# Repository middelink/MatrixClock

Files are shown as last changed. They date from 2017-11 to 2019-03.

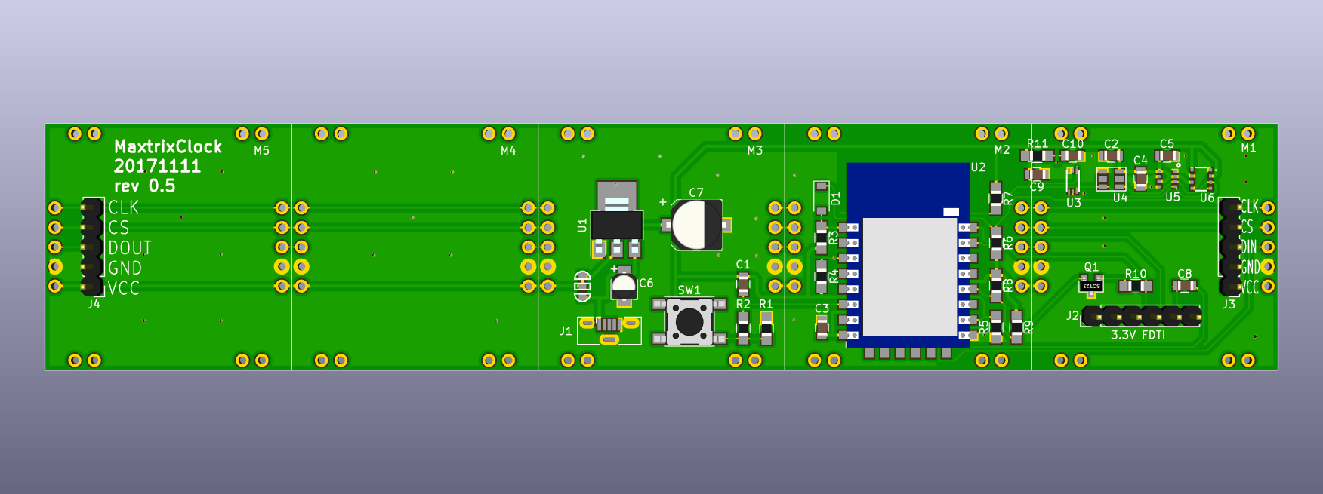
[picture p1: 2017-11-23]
KiCad/MatrixClock.png

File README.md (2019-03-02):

# MatrixClock



## TL;DR

MatrixClock is both a hardware and software project to create an extensible
40x8 dot matrix display with some sensors attached because, uhm. I could?

Here you will find the both the schematics, pcb layout and source code of my
MatrixClock project.

## Features

* Based on generaly available red 8x8 dot matrix displays with MAX7219. E.g. on [eBay](https://www.ebay.com/itm/8x8-3mm-5mm-Dot-Matrix-Display-Red-Full-Color-RGB-LED-MAX7219-DIY-Kit-f-Arduino/401374736108) (the red one, with the yellow headers).
* Full source code (arduino, platformio)
* Full schematics, PCB layout and gerbers (kicad)
* ESP-12E/F module for driving display and ntp time keeping.
* USB powered
* User defined button
* Light sensor: APDS9301 and/or BH1750FVI
* Environment sensor: BME280 or BME680
* Extensible, units can be cascaded (only one should have active components though)

## Libraries

* Adafruit's BME680 library has the nasty habbit of initializing the Wire
  library instead of leaving that to the calling program. This means they
  override our carefully set non-standard I2C pins. Needs to be commented
  out around line 104 in Adafruit\_BME680.cpp.
* Same library, Adafruit\_BME680.h, you want to comment out the include of
  Adafruit\_sensor.h. Not there, not used, not needed.

## Installation

The source is written on a Linux box and compiled/uploaded via the excellent
[PlatformIO](https://platformio.org) toolkit. The schematics and pcb layout is
created in [KiCad](https://kicad-pcb.org).

I will not bother to tell you how to compile/upload the code, modify the
schema, change the layout, create gerbers and wait patiently for the PCBs
to arrive before starting your SMD soldering adventure. Simply because
you should not do this if you not exhaustively researched all of the
just mentioned area's.

Good luck!
  Pauline

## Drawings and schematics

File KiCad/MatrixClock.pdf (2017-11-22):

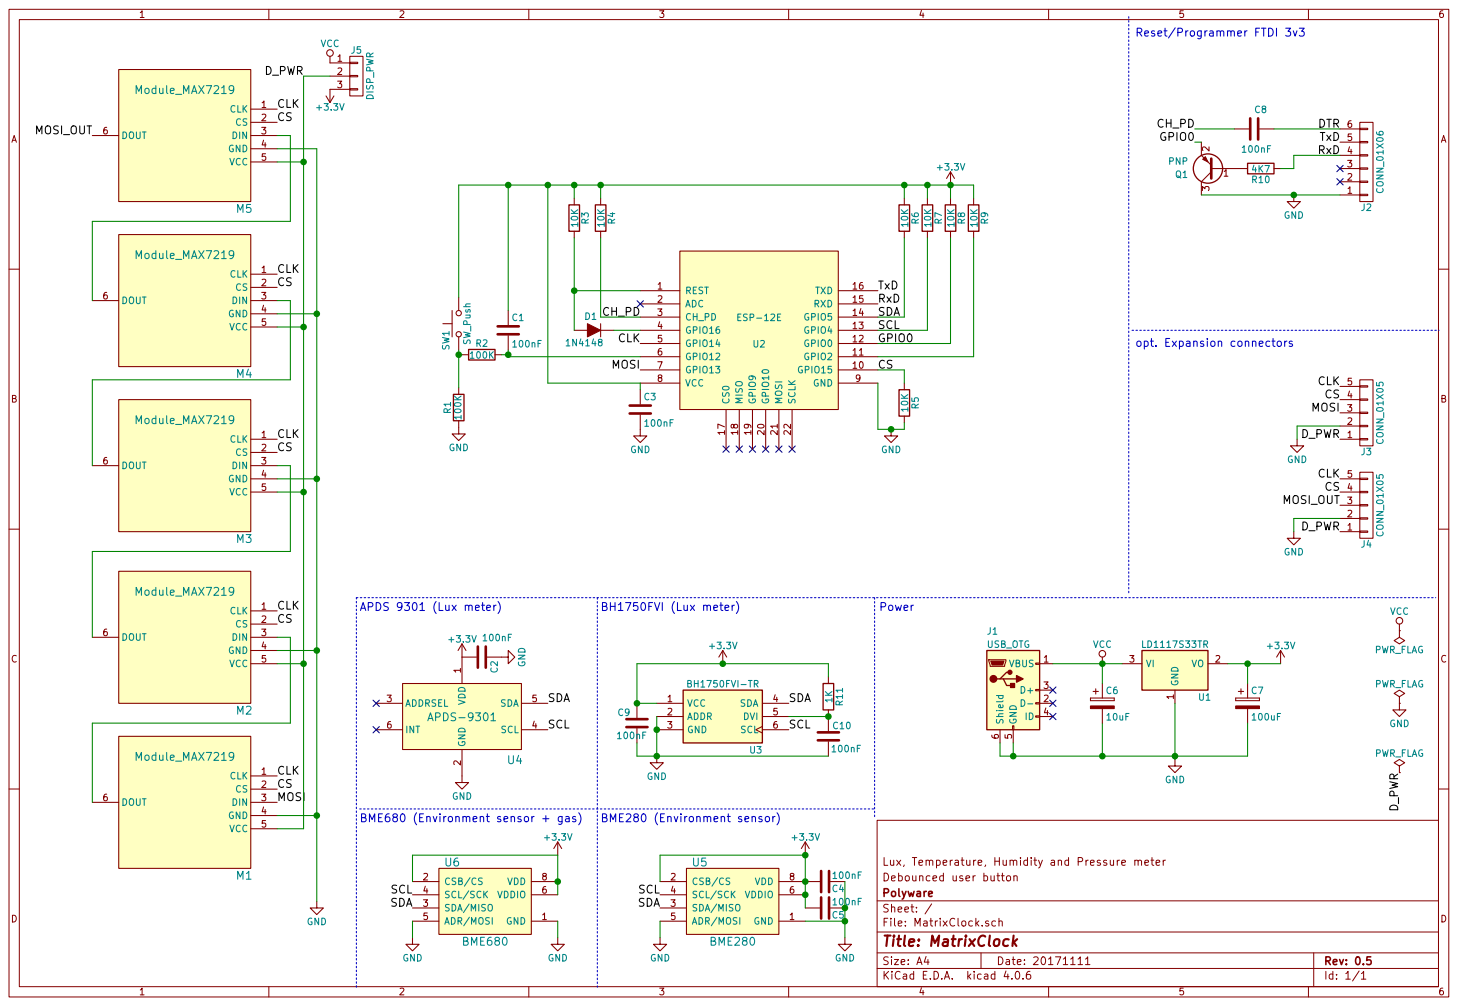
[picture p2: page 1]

BH1750FVI (Lux meter)

SCL C2 +3.3V 100nF GND

Lux, Temperature, Humidity and Pressure meter
File: MatrixClock.sch Sheet: / Polyware Debounced user button

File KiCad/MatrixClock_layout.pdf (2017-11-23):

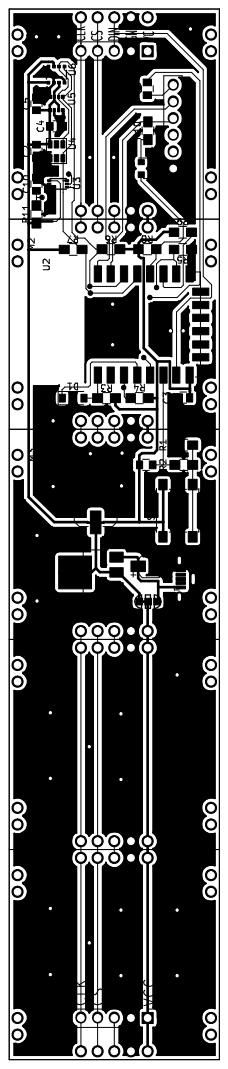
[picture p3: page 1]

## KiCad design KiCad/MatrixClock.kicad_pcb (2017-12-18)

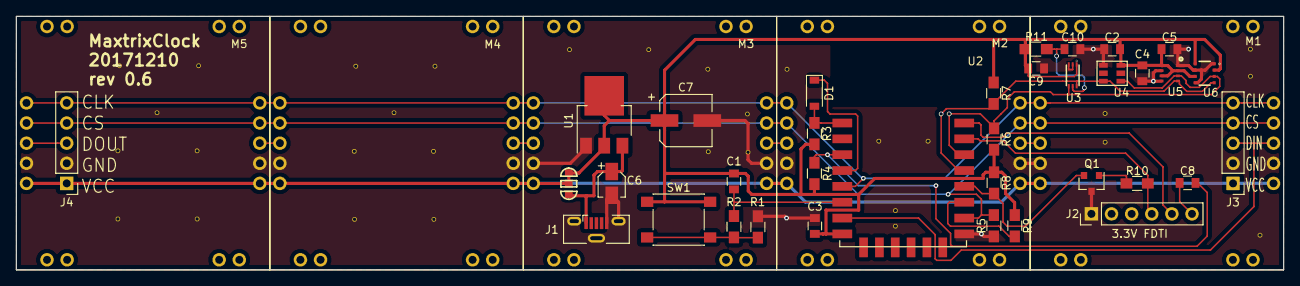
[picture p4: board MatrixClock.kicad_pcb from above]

Board: 2 copper layers, 160.0 x 32.0 mm, 70 parts (0 on the bottom side), 26 nets.

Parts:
C1, C2, C3, C4, C5, C8, C9, C10: 100nF; C_0805
C6: 10uF; CP_Elec_3x5.3
C7: 100uF; CP_Elec_6.3x5.7
D1: 1N4148; D_SOD-123
J1: USB_OTG; USB_Micro-B_Vertical_Molex-105133-0001
J2: CONN_01X06; Pin_Header_Straight_1x06_Pitch2.54mm
J3, J4: CONN_01X05; Pin_Header_Straight_1x05_Pitch2.54mm
J5: DISP_PWR; SOLDER-JUMPER_2-WAY
M1, M2, M3, M4, M5: Module_MAX7219
Q1: PNP; SOT-23
R1, R2: 100K; R_0805_HandSoldering
R3, R4, R5, R6, R7, R8, R9: 10K; R_0805_HandSoldering
R10: 4K7; R_0805_HandSoldering
R11: 1K; R_0805_HandSoldering
SW1: SW_Push; SW_SPST_PTS645
U1: LD1117S33TR; SOT-223-3Lead_TabPin2
U2: ESP-12E; ESP-12E_SMD
U3: BH1750FVI-TR; WSOF6
U4: APDS-9301; APDS9301
U5: BME280
U6: BME680
VIA01, VIA02, VIA03, VIA04, VIA05, VIA06, VIA07, VIA07#2, VIA08, VIA09, VIA10, VIA11, VIA12, VIA13, VIA14, VIA15, VIA17, VIA20, VIA21, VIA22, VIA23, VIA23#2, VIA23#3, VIA24, VIA26, VIA26#2, VIA27, VIA28, VIA29, VIA31: VIA-6mm

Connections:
+3V3: C1.1, C2.2, C3.1, C4.2, C5.2, C7.1, C9.2, J5.3, R3.1, R4.1, R6.1, R7.1, R8.1, R9.1, R11.1, SW1.1, U1.2, U2.8, U3.1, U4.1, U5.2, U5.6, U5.8, U6.2, U6.6, U6.8
/CH_PD: C8.2, R4.2, U2.3
/CLK: J3.5, J4.5, M1.1, M2.1, M3.1, M4.1, M5.1, U2.5
/CS: J3.4, J4.4, M1.2, M2.2, M3.2, M4.2, M5.2, R5.1, U2.10
/DTR: C8.1, J2.6
/D_PWR: J3.1, J4.1, J5.2, M1.5, M2.5, M3.5, M4.5, M5.5
/GPIO0: Q1.2, R8.2, U2.12
/MOSI: J3.3, M1.3, U2.7
/MOSI_OUT: J4.3, M5.6
/RxD: J2.4, R10.1, U2.15
/SCL: R7.2, U2.13, U3.6, U4.4, U5.4, U6.4
/SDA: R6.2, U2.14, U3.4, U4.5, U5.3, U6.3
/TxD: J2.5, U2.16
GND: C2.1, C3.2, C4.1, C5.1, C6.2, C7.2, C9.1, C10.1, J1.5, J1.6, J2.1, J3.2, J4.2, M1.4, M2.4, M3.4, M4.4, M5.4, Q1.3, R1.1, R5.2, U1.1, U2.9, U3.2, U3.3, U4.2, U5.1, U5.5, U5.7, U6.1, U6.5, U6.7, VIA01.1, VIA02.1, VIA03.1, VIA04.1, VIA05.1, VIA06.1, VIA07.1, VIA07#2.1, VIA08.1, VIA09.1, VIA10.1, VIA11.1, VIA12.1, VIA13.1, VIA14.1, VIA15.1, VIA17.1, VIA20.1, VIA21.1, VIA22.1, VIA23.1, VIA23#2.1, VIA23#3.1, VIA24.1, VIA26.1, VIA26#2.1, VIA27.1, VIA28.1, VIA29.1, VIA31.1
unnamed: C1.2, R2.1, U2.6
unnamed: C10.2, R11.2, U3.5
unnamed: D1.1, U2.4
unnamed: D1.2, R3.2, U2.1
unnamed: M1.6, M2.3
unnamed: M2.6, M3.3
unnamed: M3.6, M4.3
unnamed: M4.6, M5.3
unnamed: Q1.1, R10.2
unnamed: R1.2, R2.2, SW1.2
unnamed: R9.2, U2.11
VCC: C6.1, J1.1, J5.1, U1.3

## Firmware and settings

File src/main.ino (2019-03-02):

// vim:softtabstop=4:shiftwidth=4:tabstop=64:filetype=cpp
#include <ESP8266WiFi.h>
#include <ESP8266mDNS.h>
#include <ArduinoOTA.h>
#include <FS.h>
#include <Ticker.h>
#include <Wire.h> 
#include <SPI.h>
#include <time.h>
#include <list>

#include "MD_MAX72xx.h"
#include <ArduinoJson.h>
#include <WiFiManager.h> 
#include <PubSubClient.h>
#include <Bounce2.h>
#include "apds9301.h"
#include <Adafruit_BME680.h>
#include <BH1750.h>
#include <BME280I2C.h>
#include <EnvironmentCalculations.h>

#define HAS_APDS9301  // Light meter
#define HAS_BH1750    // Light meter
#define HAS_BME280    // Env meter
#define HAS_BME680    // Env meter + gas

/* constants */
constexpr auto _SDA = 5;
constexpr auto _SCL = 4;

constexpr char tz[] = "TZ=CET-1CEST-2,M3.5.0/02:00:00,M10.5.0/03:00:00";

constexpr auto BUTTON = 12;

/* global variables */
MD_MAX72XX leds(SS, 5);
Ticker ticker1;
Bounce bouncy;
int display_mode;
int display_time;
bool show_time;

//define your default values here, if there are different values in config.json, they are overwritten.
String mqtt_server("rp1.ch.polyware.nl");
String mqtt_port("1883");
bool shouldSaveConfig;

uint32_t press_time;
uint32_t delay_next;
uint32_t delay_next_sensors;
#if defined(HAS_BME280) || defined(HAS_BME680)
enum {
    ENV_UNKNOWN,
    ENV_BME280,
    ENV_BME680,
} bme;
#endif
#if defined(HAS_APDS9301) || defined(HAS_BH1750)
enum {
    LUX_UNKNOWN,
    LUX_APDS9301,
    LUX_BH1750,
} lux;
#endif
#ifdef HAS_APDS9301
LuxI2C_APDS9301 apds(0x39);
#endif
#ifdef HAS_BH1750
BH1750 bh;
#endif
#ifdef HAS_BME280
BME280I2C bme280(BME280I2C::Settings{
    /*tosr=*/BME280::OSR_X1,
    /*hosr=*/BME280::OSR_X1,
    /*posr=*/BME280::OSR_X1,
    /*mode=*/BME280::Mode_Forced,
    /*st=*/BME280::StandbyTime_1000ms,
    /*filter=*/BME280::Filter_Off,
    /*spiEnable=*/BME280::SpiEnable_False,
    /*bme_280_addr=*/BME280I2C::I2CAddr::I2CAddr_0x76});
#endif
#ifdef HAS_BME680
Adafruit_BME680 bme680;
#endif
String mqtt_prefix;
WiFiClient wificlient;
PubSubClient mqtt("", 0, wificlient);

// Setup ESP to measure VCC
ADC_MODE(ADC_VCC);

void setString(const char* msg) {
    int offset = leds.getColumnCount()-1;
    leds.control(MD_MAX72XX::UPDATE, MD_MAX72XX::OFF);
    leds.clear();
    while (char ch = *msg++) {
        offset -= leds.setChar(offset, ch) + 1;
    }
    leds.control(MD_MAX72XX::UPDATE, MD_MAX72XX::ON);
}

void setString(float val, const char suffix[]) {
    String s(val, 0);
    s += suffix;

    int offset = -2;
    uint8_t buf[8];
    for (const auto &ch : s) {
        offset += leds.getChar(ch, sizeof(buf), buf) + 1;
    }
    for (const auto &ch : s) {
        offset -= leds.setChar(offset, ch) + 1;
    }
}

struct {
    float volt;
    float lux;
    float temp;
    float hum;
    float dew;
    float pres;
    float gas_r;
} sensors;

void showTime(void) {
    time_t now = time(nullptr);
    if (now == 0)
        return;
    struct tm *tm = localtime(&now);

    show_time = true;

    leds.control(MD_MAX72XX::UPDATE, MD_MAX72XX::OFF);
    leds.clear();
    switch (display_mode) {
        case 4: // Temp
            setString(sensors.temp, "\775C");
            if (--display_time == 0) {
                display_mode--;
                display_time = 5;
            }
            break;
        case 3: // RH
            setString(sensors.hum, " RH");
            if (--display_time == 0) {
                display_mode--;
                display_time = 5;
            }
            break;
        case 2: // hPA
            setString(sensors.pres, " hPa");
            if (--display_time == 0) {
                display_mode--;
                display_time = 5;
            }
            break;
        case 1: // Lux
            setString(sensors.lux, " lx");
            if (--display_time == 0) {
                display_mode--;
                display_time = 5;
            }
            break;
        case 0:
            leds.setChar(38, '0'+(tm->tm_hour/10)%10);
            leds.setChar(32, '0'+(tm->tm_hour/ 1)%10);
            leds.setChar(26, ':');
            leds.setChar(24, '0'+(tm->tm_min/10)%10);
            leds.setChar(18, '0'+(tm->tm_min/ 1)%10);
            leds.setChar(12, ':');
            leds.setChar(10, '0'+(tm->tm_sec/10)%10);
            leds.setChar( 4, '0'+(tm->tm_sec/ 1)%10);
            break;
    }
    leds.control(MD_MAX72XX::UPDATE, MD_MAX72XX::ON);
}

void readSensors() {
    sensors.volt = ESP.getVcc()/1024.0;

#if defined(HAS_APDS9301) || defined(HAS_BH1750)
    switch (lux) {
        case LUX_UNKNOWN:
            sensors.lux = NAN;
            break;
#ifdef HAS_APDS9301
        case LUX_APDS9301:
            sensors.lux = apds.getLux();
            break;
#endif
#ifdef HAS_BH1750
        case LUX_BH1750:
            sensors.lux = bh.readLightLevel();
            break;
#endif
    }
#endif

#if defined(HAS_BME280) || defined(HAS_BME680)
    switch (bme) {
#ifdef HAS_BME280
        case ENV_BME280: {
                    bme280.read(sensors.pres, sensors.temp, sensors.hum, BME280::TempUnit_Celsius, BME280::PresUnit_hPa);
                    sensors.gas_r = NAN;
                }
                break;
#endif
#ifdef HAS_BME680
        case ENV_BME680: {
                    bme680.performReading();
                    sensors.temp = bme680.temperature;
                    sensors.hum = bme680.humidity;
                    sensors.pres = bme680.pressure / 100.0;
                    sensors.gas_r = bme680.gas_resistance;
                }
                break;
#endif
        case ENV_UNKNOWN:
                /* ignore */
                break;
    }
    sensors.dew = EnvironmentCalculations::DewPoint(sensors.temp, sensors.hum, EnvironmentCalculations::TempUnit_Celsius);
#endif
}

void writeSensors() {
#if MQTT_MAX_PACKET_SIZE < 256
#error "Please define MQTT_MAX_PACKET_SIZE larger or equal to 256."
#endif
    StaticJsonBuffer<200> jsonBuffer;
    JsonObject& root = jsonBuffer.createObject();

#if defined(HAS_APDS9301) || defined(HAS_BH1750)
    if (!isnan(sensors.lux)) {
        root["lux"] = sensors.lux;
        if (!mqtt.publish((mqtt_prefix+"/lux").c_str(), String(sensors.lux).c_str())) {
            Serial.println("Publish lux failed");
        }
    }
#endif
#if defined(HAS_BME280) || defined(HAS_BME680)
    root["temperature"] = sensors.temp;
    if (!mqtt.publish((mqtt_prefix+"/temperature").c_str(), String(sensors.temp).c_str())) {
        Serial.println("Publish temperature failed");
    }
    root["humidity"] = sensors.hum;
    if (!mqtt.publish((mqtt_prefix+"/humidity").c_str(), String(sensors.hum).c_str())) {
        Serial.println("Publish humidity failed");
    }
    root["dewpoint"] = sensors.dew;
    if (!mqtt.publish((mqtt_prefix+"/dewpoint").c_str(), String(sensors.dew).c_str())) {
        Serial.println("Publish dewpoint failed");
    }
    root["pressure"] = sensors.pres;
    if (!mqtt.publish((mqtt_prefix+"/pressure").c_str(), String(sensors.pres).c_str())) {
        Serial.println("Publish pressure failed");
    }
#ifdef HAS_BME680
    if (!isnan(sensors.gas_r) && sensors.gas_r > 1.0) {
        root["gas_resistance"] = sensors.gas_r;
        if (!mqtt.publish((mqtt_prefix+"/gas_resistance").c_str(), String(sensors.gas_r).c_str())) {
            Serial.println("Publish gas_resistance failed");
        }
    }
#endif
#endif
    root["voltage"] = sensors.volt;
    if (!mqtt.publish((mqtt_prefix+"/voltage").c_str(), String(sensors.volt).c_str())) {
        Serial.println("Publish voltage failed");
    }
    root["reset"] = ESP.getResetReason();
    if (!mqtt.publish((mqtt_prefix+"/reset_reason").c_str(), ESP.getResetReason().c_str())) {
        Serial.println("Publish reset failed");
    }
    root["id"] = String(ESP.getChipId(), HEX);
    String json;
    root.printTo(json);
    if (!mqtt.publish((mqtt_prefix+"/json").c_str(), json.c_str())) {
        Serial.println("Publish json failed");
    }
    Serial.print("json="); Serial.println(json);
}

bool mqtt_setup() {
    Serial.println("Attempting MQTT connection...");
    // Attempt to connect
    setString("Mqtt...");
    if (mqtt.connect(WiFi.hostname().c_str(), (mqtt_prefix+"/status").c_str(), MQTTQOS0, true, "died")) {
        Serial.println("Connected to MQTT broker");
        // Once connected, publish an announcement...
        if (!mqtt.publish((mqtt_prefix+"/status").c_str(), "online", true)) {
            Serial.println("Publish-hello failed");
        }
        setString("Mqtt OK");
        return true;
    }
    setString("Mqtt BAD");
    Serial.print("failed, rc=");
    Serial.println(mqtt.state());
    return false;
}

bool wifi_setup() {
    //read configuration from FS (json)
    Serial.println("mounting FS...");
    if (SPIFFS.begin()) {
        Serial.println("mounted file system");
        if (SPIFFS.exists("/config.json")) {
            //file exists, reading and loading
            Serial.println("reading config file");
            File configFile = SPIFFS.open("/config.json", "r");
            if (configFile) {
                Serial.println("opened config file");
                DynamicJsonBuffer jsonBuffer;
                JsonObject& json = jsonBuffer.parseObject(configFile);
                json.printTo(Serial);
                if (json.success()) {
                    Serial.println("\nparsed json");

                    mqtt_server = json["mqtt_server"].as<String>();
                    mqtt_port = json["mqtt_port"].as<String>();
                } else {
                    Serial.println("failed to load json config");
                }
            }
        }
    } else {
        Serial.println("failed to mount FS");
    }

    // The extra parameters to be configured (can be either global or just in the setup)
    // After connecting, parameter.getValue() will get you the configured value
    // id/name placeholder/prompt default length
    WiFiManagerParameter custom_mqtt_server("server", "mqtt server", mqtt_server.c_str(), 40);
    WiFiManagerParameter custom_mqtt_port("port", "mqtt port", mqtt_port.c_str(), 5);

    setString("Wifi...");
    WiFiManager wifiManager;
    // Set a long timeout, last night I rebooted my AP and all the
    // sensors jumped into AP mode due to lack of connection and I had
    // to manually reset them. Ouch.
    wifiManager.setConfigPortalTimeout(90);
    wifiManager.setConnectTimeout(90);
    wifiManager.setAPCallback([](WiFiManager *wifi) {
        setString("Wifi AP");
    });
    // Set config save notify callback
    shouldSaveConfig = false;
    wifiManager.setSaveConfigCallback([]() {
            shouldSaveConfig = true;
    });

    // Add all your parameters here
    wifiManager.addParameter(&custom_mqtt_server);
    wifiManager.addParameter(&custom_mqtt_port);

    ticker1.detach();
    auto res = wifiManager.autoConnect();
    ticker1.attach_ms(1000, showTime);
    if (res) {
        setString("Wifi OK");
        // It seems AP stays on after we left the portal.
        WiFi.mode(WIFI_STA);
    } else {
        setString("Wifi BAD");
        Serial.println("failed to connect or hit timeout");
        delay(3000);
        // Reset and try again, or maybe put it to deep sleep
        ESP.reset();
        delay(5000);
        return false;
    }

    // Read updated parameters
    mqtt_server = custom_mqtt_server.getValue();
    mqtt_port = custom_mqtt_port.getValue();
    mqtt.setServer(mqtt_server.c_str(), mqtt_port.toInt());

    // Save the custom parameters to FS
    if (shouldSaveConfig) {
        Serial.println("saving config");
        DynamicJsonBuffer jsonBuffer;
        JsonObject& json = jsonBuffer.createObject();
        json["mqtt_server"] = mqtt_server;
        json["mqtt_port"] = mqtt_port;

        File configFile = SPIFFS.open("/config.json", "w");
        if (!configFile) {
            Serial.println("failed to open config file for writing");
        }

        json.printTo(Serial);
        json.printTo(configFile);
        configFile.close();
    }
    SPIFFS.end();

    return res;
}

void setup() {
    mqtt_prefix = "esp8266/" + String(ESP.getChipId(), HEX);

    Serial.begin(76800);

    leds.begin();
    leds.control(MD_MAX72XX::INTENSITY, MAX_INTENSITY/6);

    putenv(const_cast<char *>(tz));
    tzset();
    configTime(0, 0, "0.centos.pool.ntp.org", "1.centos.pool.ntp.org", "2.centos.pool.ntp.org");

    // Start I2C bus on our own pins.
    Wire.begin(_SDA, _SCL);
    //Wire.setClock(100000);

//===========
    Serial.print("chip_id="); Serial.println(ESP.getChipId(), HEX);
    Serial.print("flash_id="); Serial.println(ESP.getFlashChipId(), HEX);
    Serial.print("flash_size="); Serial.println(ESP.getFlashChipRealSize());
    Serial.print("mac="); Serial.println(WiFi.macAddress());
//===========

    Serial.println("Scanning i2c bus...");
    uint8_t data = 0;
    for (uint8_t addr = 1; addr < 128; addr++) {
        auto rc = twi_writeTo(addr, &data, /*len=*/0, /*send_stop=*/true);
        if (rc == 0 ) {
            switch (addr) {
#ifdef HAS_APDS9301
                case 0x29:
                case 0x39:
                case 0x49:
                    if (lux == LUX_UNKNOWN) {
                        lux = LUX_APDS9301;
                        apds.powerOn();
                        apds.setADCGain(LuxI2C_APDS9301::low_gain);
                        // apds.setIntegrationTime(LuxI2C_APDS9301::low_time);
                        // apds.setIntegrationTime(LuxI2C_APDS9301::medium_time);
                        apds.setIntegrationTime(LuxI2C_APDS9301::high_time);
                        Serial.printf("APDS-9301: part=%02x, rev=%02x\n", apds.getPartNum(), apds.getRevNum());
                    } else {
                        Serial.println("Skipping APDS-9301");
                    }
                    break;
#endif
#ifdef HAS_BH1750
                case 0x23:
                case 0x5C:
                    if (lux == LUX_UNKNOWN) {
                        lux = LUX_BH1750;
                        bh.begin();
                        Serial.println("BH1750FVI");
                    } else {
                        Serial.println("Skipping BH1750FVI");
                    }
                    break;
#endif
#if defined(HAS_BME280) || defined(HAS_BME680)
                case 0x76:
                case 0x77:
                    if (!bme280.begin()) {
                        if (!bme680.begin(addr)) {
                            delay(5);
                            if (!bme280.begin()) {
                                if (!bme680.begin(addr)) {
                                    Serial.println("Unable to locate either BME280 or BME680");
                                }
                            }
                        } else {
                            Serial.println("BME680");
                            bme = ENV_BME680;
                        }
                    } else {
                        Serial.printf("BME280: chip=%02x\n", bme280.chipModel());
                        bme = ENV_BME280;
                    }
                    break;
#endif
            }
        }
        delay(1);
    }
//===========

    ArduinoOTA.onStart([]() {
        ticker1.detach();
        Serial.println("OTA Start");
        setString("OTA");
    });
    ArduinoOTA.onEnd([]() {
        Serial.println("\nOTA End");
        setString("OTA OK");
        // Reboot will restart the timer for us.
    });
    ArduinoOTA.onProgress([](unsigned int progress, unsigned int total) {
        Serial.printf("Progress: %u%%\r", (progress / (total / 100)));
        setString("OTA...");
    });
    ArduinoOTA.onError([](ota_error_t error) {
        ticker1.attach_ms(1000, showTime);
        Serial.printf("Error[%u]: ", error);
        if (error == OTA_AUTH_ERROR) Serial.println("Auth Failed");
        else if (error == OTA_BEGIN_ERROR) Serial.println("Begin Failed");
        else if (error == OTA_CONNECT_ERROR) Serial.println("Connect Failed");
        else if (error == OTA_RECEIVE_ERROR) Serial.println("Receive Failed");
        else if (error == OTA_END_ERROR) Serial.println("End Failed");
        setString("OTA error");
    });
    ArduinoOTA.setPassword("NoWay");
    //ArduinoOTA.setHostname(WiFi.hostname().c_str());
    ArduinoOTA.begin();

    ticker1.attach_ms(1000, showTime);

    // Explicitly set button to input even though it already should be.
    pinMode(BUTTON, INPUT);
    // After setting up the button, setup the Bounce instance
    bouncy.attach(BUTTON);
    bouncy.interval(5);
}

void loop() {
    ArduinoOTA.handle();
    bouncy.update();

    if (show_time) {
        show_time = false;

        time_t now = time(nullptr);
        Serial.print(ctime(&now));
    }

    auto now = millis();
    // Try to connect to network every 30 seconds.
    if (WiFi.status() != WL_CONNECTED) {
        if (delay_next < now) {
            if (!wifi_setup()) {
                // no network? retry in 30s.
                delay_next = now + 30000;
                return;
            }
            delay_next = now;
        }
        return;
    }

    // Now we have network, try mqtt every 10 seconds.
    if (mqtt_server.length()) {
        if (!mqtt.loop()) {
            if (delay_next < now) {
                if (!mqtt_setup()) {
                     // no mqtt? retry in 10s.
                     delay_next = now + 10000;
                     return;
                }
                delay_next = now;
            }
            return;
        }
    }

    // Tick-tock on the state machine
    if (delay_next_sensors < now) {
        delay_next_sensors = now + 5*60*1000;

        // Always read the sensors, but only write them to mqtt if we have a server.
        readSensors();
        if (mqtt_server.length()) {
            writeSensors();
        }
    }

    // Check for button changes.
    if (bouncy.rose()) {
        press_time = now;
    } else if (bouncy.fell()) {
        press_time = now - press_time;
        Serial.printf("Button pressed %dms ago\n", press_time);
        if (press_time > 2000) {
            Serial.println("Disconnecting WiFi");
            WiFi.disconnect();
            return;
        }
        display_mode = 4;
        display_time = 5;
    }

    // Process serial port bytes
    if (Serial.available()) {
        switch (Serial.read()) {
         case ' ':
            {
                Serial.println("Scanning...");
                uint8_t data = 0;
                for (uint8_t addr = 1; addr < 128; addr++) {
                    auto rc = twi_writeTo(addr, &data, /*len=*/0, /*send_stop=*/true);
                    if (rc == 0 ) {
                        Serial.print("addr: ");
                        Serial.println(addr, HEX);
                    }
                    delay(1);
                }
                Serial.println();
            }
            break;
         case 's':
            readSensors();
            Serial.printf("volt=%.2f", sensors.volt);
            Serial.printf(", lux=%.2f", sensors.lux);
            Serial.printf(", temp=%.2f", sensors.temp);
            Serial.printf(", hum=%.2f", sensors.hum);
            Serial.printf(", dew=%.2f", sensors.dew);
            Serial.printf(", pres=%.2f", sensors.pres);
            Serial.printf(", gas=%.2f\n", sensors.gas_r);
            break;
        }
    }
}

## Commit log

2017-11-22 Initial commit of rev 0.3
    [MatrixClock.kicad_pcb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]
2017-11-22 Bumped version to 0.5
    Features:
    * Reworked the matrix module layout, the 2 header pins where 0.4mm off.
    * Added BH1750FVI as an alternative light sensor.
    Fixed issues:
    * R10 should be connected to RX, not TX (seen from ESP12, not FTDI connector)
    [MatrixClock.kicad_pcb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]
2017-11-23 Same revision, regenerated GERBER files and re-added .png and .zip for easy submitting to your fav pcbfab studio.
    [MatrixClock.kicad_pcb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]
2017-11-25 Set (long) timeout on Wifimanager, to handle rebooting APs and have all your clocks/sensors jump into AP mode.
    Updated .gitignore to ignore platformio's build directories.
    [main.ino]
2017-12-08 Remove unneeded mqtt_subscribe Add BH1750FVI light sensor option in rev 0.5
2017-12-18 New release 0.6, discovered a stray stitch via in the middle of the regulator solder pad. Moved other stitch via's around for a more visual appealing pattern ^^
    [MatrixClock.kicad_pcb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]
2019-03-02 Update build files to new world. Fixed some small issues with wifimanager timeouts.
    [main.ino]
